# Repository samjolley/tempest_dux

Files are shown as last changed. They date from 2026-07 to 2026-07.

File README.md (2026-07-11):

# Tempest Dux

A wireless split ergonomic keyboard with an integrated trackball. Thirty-six keys, low-profile Choc switches, nice!nano v2, nice!view display, and a PMW3610 trackball on the right half.

This is my build. I did not design it from scratch, and the credits below matter.

## Lineage and credits

- **Ergonomics:** the dux family, Rae-Dux and Architeuthis Dux.
- **Base design and visual theme:** [thrly's Tempest](https://github.com/thrly/tempest).
- **Firmware base:** [Manna Harbour's Miryoku](https://github.com/manna-harbour/miryoku) for ZMK.
- **Trackball driver:** [badjeff's PMW3610 module](https://github.com/badjeff/zmk-pmw3610-driver).

## What is mine

Built on that lineage, my own contribution is:

- a custom PCB laid out with Ergogen and finished in KiCad (matrix, MCU, display, power, and the trackball cluster),
- the integrated PMW3610 trackball on the right half, its socket, and the printed housing,
- custom outlines and multi-layer 3D-printed plates and case,
- the ZMK firmware integration that makes the trackball a first-class input alongside the keys.

## Status

- **v0.6.56** boards fabricated and in assembly and bring-up.
- **v0.7.x** in progress: the reversible board architecture is dropped in favor of separate left and right files, with mounting-hole clearance, test points, and a dual-face ground pour on the errata list.

## Build log

I wrote up the design decisions, the failures, and what I would do differently here: <https://samjolley.com/writing/building-the-tempest-dux/>

## License

My original work here (the Ergogen config, the KiCad board, and my custom footprints) is released under the MIT License; see [LICENSE](LICENSE). Bundled third-party components keep their own licenses: the `ceoloide` Ergogen footprints under `ergogen/footprints/ceoloide/` retain the license headers in each file. This design builds on the prior art credited above, which carries its own terms where stated.

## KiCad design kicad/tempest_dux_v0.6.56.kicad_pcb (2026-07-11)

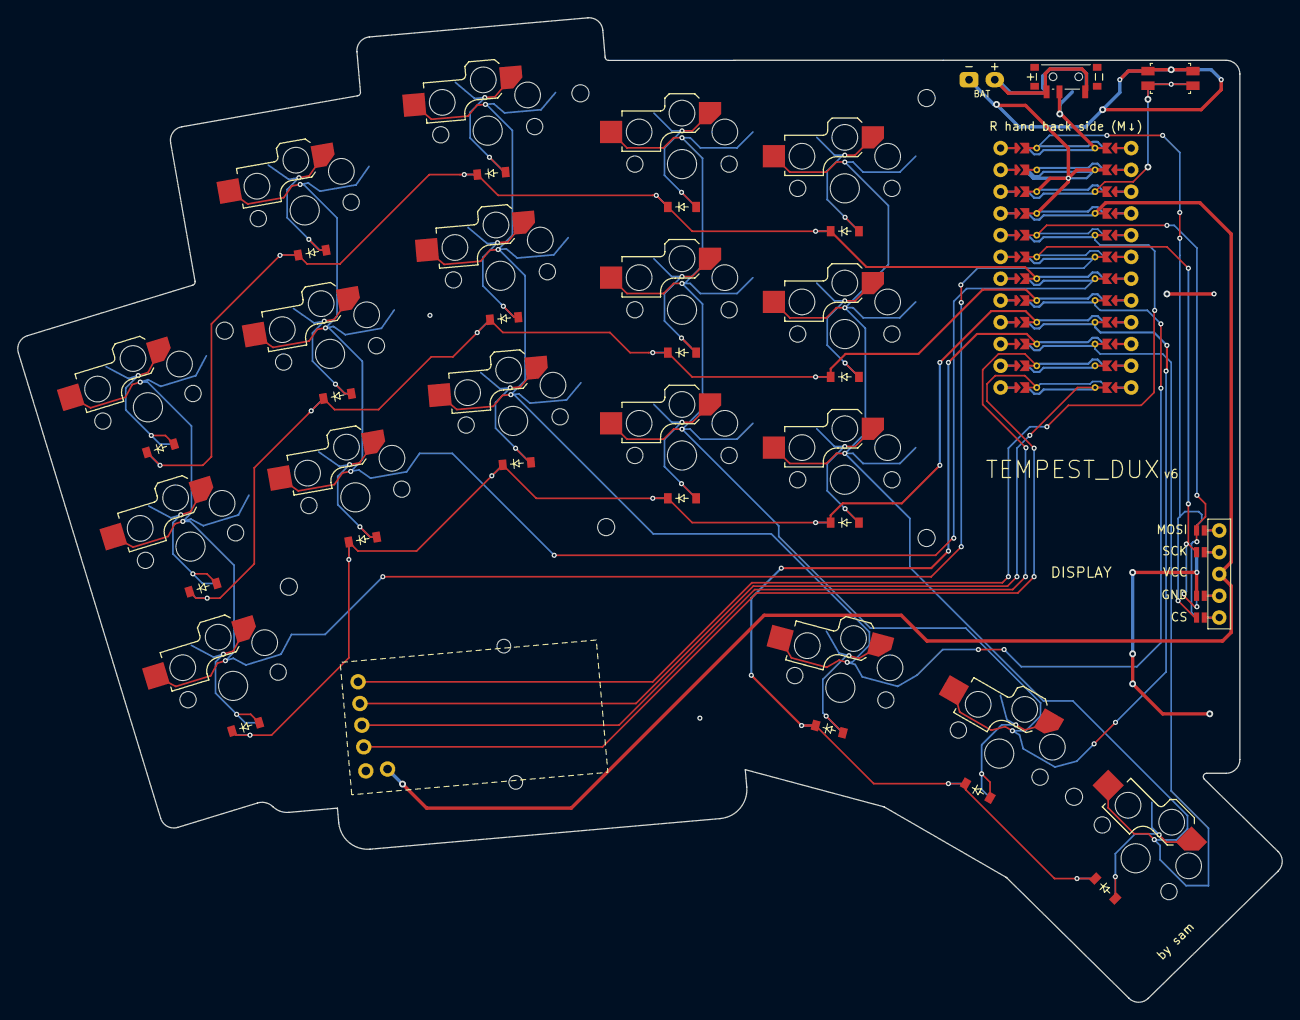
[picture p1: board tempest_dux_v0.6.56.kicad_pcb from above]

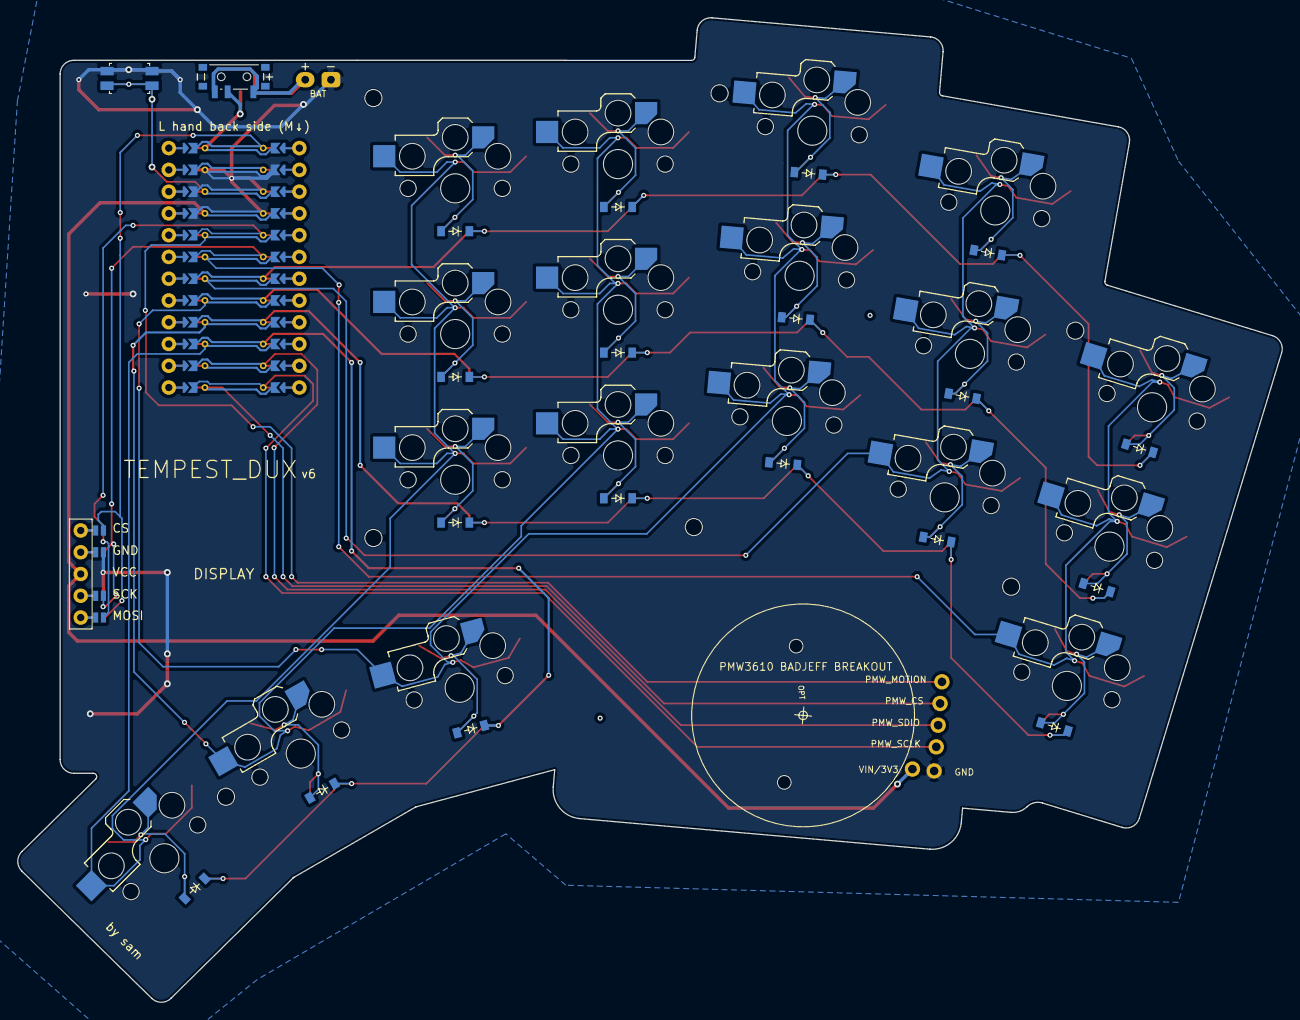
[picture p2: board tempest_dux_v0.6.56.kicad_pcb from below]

Board: 2 copper layers, 147.6 x 114.9 mm, 50 parts (18 on the bottom side), 43 nets.

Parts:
BAT1: battery_direct_solder_reversible
D1, D2, D3, D4, D5, D6, D7, D8, D9, D10, D11, D12, D13, D14, D15, D16, D17, D18: diode_tht_sod123
DISP1: display_nice_view
MCU1: mcu_nice_nano
MH1, MH2, MH3, MH4, MH5, MH6, MH7: mounting_hole_npth
PMW1: badjeff PMW3610 breakout socket; pmw3610_badjeff_socket
PWR1: power_switch_smd_side
RST1: reset_switch_smd_side
S1, S2, S3, S4, S5, S6, S7, S8, S9, S10, S11, S12, S13, S14, S15, S16, S17, S18: switch_choc_v1_v2
TB: keyball_34mm_case; keyball_trackball_case_34mm

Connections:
BAT_P: BAT1.2, PWR1.1, PWR1.3
CS: DISP1.14, DISP1.24, MCU1.124
DISP1_1: DISP1.1, DISP1.10, DISP1.23
DISP1_2: DISP1.2, DISP1.11, DISP1.22
DISP1_4: DISP1.4, DISP1.12, DISP1.21
DISP1_5: DISP1.5, DISP1.13, DISP1.20
GND: BAT1.1, DISP1.15, DISP1.25, MCU1.102, MCU1.121, MCU1.122, PMW1.GND, RST1.1, RST1.3
MOSI: DISP1.17, DISP1.27, MCU1.120
PMW_CS: MCU1.112, PMW1.CS
PMW_MOTION: MCU1.105, PMW1.MOTION
PMW_SCLK: MCU1.113, PMW1.SCLK
PMW_SDIO: MCU1.114, PMW1.SDIO
RAW: MCU1.101, PWR1.2
RST: MCU1.103, RST1.2, RST1.4
SCK: DISP1.16, DISP1.26, MCU1.119
VCC: DISP1.3, MCU1.104, PMW1.VIN
col_index: MCU1.109, S10.2, S11.2, S12.2, S17.2
col_inner: MCU1.110, S13.2, S14.2, S15.2, S18.2
col_middle: MCU1.108, S7.2, S8.2, S9.2, S16.2
col_pinky: MCU1.106, S1.2, S2.2, S3.2
col_ring: MCU1.107, S4.2, S5.2, S6.2
far_thumb-cluster: D18.2, S18.1
index_bottom: D10.2, S10.1
index_home: D11.2, S11.1
index_top: D12.2, S12.1
inner_bottom: D13.2, S13.1
inner_home: D14.2, S14.1
inner_top: D15.2, S15.1
mid_thumb-cluster: D17.2, S17.1
middle_bottom: D7.2, S7.1
middle_home: D8.2, S8.1
middle_top: D9.2, S9.1
near_thumb-cluster: D16.2, S16.1
pinky_bottom: D1.2, S1.1
pinky_home: D2.2, S2.1
pinky_top: D3.2, S3.1
ring_bottom: D4.2, S4.1
ring_home: D5.2, S5.1
ring_top: D6.2, S6.1
row_bottom: D1.1, D4.1, D7.1, D10.1, D13.1, MCU1.116
row_home: D2.1, D5.1, D8.1, D11.1, D14.1, MCU1.117
row_thumb: D16.1, D17.1, D18.1, MCU1.115
row_top: D3.1, D6.1, D9.1, D12.1, D15.1, MCU1.118

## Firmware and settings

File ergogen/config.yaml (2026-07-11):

# ===============================================================================
# TEMPEST_DUX - wireless split ergonomic keyboard with integrated PMW3610 trackball
# -------------------------------------------------------------------------------
# Lineage : rae-dux / track-dux column geometry (validated on Sam's daily driver)
# Stack   : ergogen v4.2.1 -> KiCad 8 -> JLCPCB ;  ZMK on nRF52840 (nice!nano v2)
# Repo    : https://github.com/samjolley/tempest_dux
#
# -- v0.7.x ARCHITECTURE: two dedicated single-sided boards (NOT reversible) -----
# The old reversible board (one gerber, flipped, peripherals DNP per side) is gone.
# v0.7 splits into two distinct single-sided gerbers generated from ONE points
# tree via an ergogen global mirror:
#
#     SOURCE hand (unprefixed pts: matrix_*, thumb_*) = LEFT  half = DISPLAY
#     MIRROR hand (mirror_* pts)                       = RIGHT half = TRACKBALL
#
# Handedness is verified, not assumed: in the source hand the pinky is leftmost and
# the inner column rightmost => that is the LEFT hand. The mirror is therefore the
# RIGHT hand, which carries the trackball. Do not swap these.
#
# -- MIRROR MECHANISM (read before editing geometry) ----------------------------
#   points.mirror: {ref: matrix_inner_home, distance: 160}  -> emits mirror_* pts.
#   ergogen does the reflection (x flipped, rotation negated), so there is NO manual
#   KiCad mirror step. The reflection is exact, incl. the asymmetric thumb cluster.
#
#   Hand isolation uses POSITIVE name regex on `where`:
#       source/left  : where: /^(matrix_|thumb_).*/
#       mirror/right : where: /^mirror_(matrix_|thumb_).*/
#   WARNING: do NOT use a negative lookahead like /^(?!mirror)/ - ergogen does not
#   honor it; it silently matches BOTH hands and the board spans both halves.
#   Single-point footprints use the matching ref prefix: left = matrix_inner_home,
#   right = mirror_matrix_inner_home, etc.
#
# -- ELECTRONICS / PINOUT (one ZMK keymap serves both halves) --------------------
#   Matrix rows : P4 P5 P6 P7          (identical both boards)
#   Matrix cols : P14 P15 P18 P19 P20  (identical both boards)
#   Display SPI : P1=CS  P2=MOSI P3=SCK                  -> LEFT board only
#   PMW3610 SPI : P10=CS P9=SCLK P8=SDIO P21=MOTION (3-wire) -> RIGHT board only
#   elec_* units (top of `units`) tune shared X/Y placement; elec_switch_right_x
#   adds a +1.4mm X nudge for the rotated SMD side power switch on the RIGHT only.
#
# -- OUTLINES & PLATES -----------------------------------------------------------
#   Source outlines (display_board_outline, keyboard_body, left_bottom_plate_outline)
#     = LEFT board (no trackball lobe).
#   right_* outlines (right_trackball_board_outline, right_bottom_plate_outline)
#     = RIGHT board (trackball lobe + cleanout).
#   Switch/top/TPU/back plates are built from the SOURCE (left) hand and are
#   symmetric - mirror them in the slicer for the right half. Bottom plates are
#   per-hand; only the right one has the trackball cleanout.
#
# -- PRE-ORDER CHECKLIST (custom footprints + DRC are not checkable from YAML) ----
#   [ ] 1:1 paper print BOTH halves; confirm key + trackball + thumb fit.
#   [ ] KiCad: switches/diodes/hotswap all on the same physical side (B.Cu) on BOTH
#       boards - confirm the mirror did not flip any footprint to F.Cu.
#   [ ] Confirm reverse_mount:true on the MCU is intended; check USB-C direction.
#   [ ] Verify right power switch (rotate 180 + elec_switch_right_x) position.
#   [ ] Custom footprints resolve: pmw3610_badjeff_socket, keyball_trackball_case_34mm,
#       TentingPuck, choc_hotswap_plate_cutout, smd_plate_cutout.
#   [ ] DRC clean on both boards (vias at 0.6/0.3mm sit at min annular ring).
#
# -- CHANGELOG -------------------------------------------------------------------
#   v0.7.5 : silk ver -> v0.7.5; branding text consolidated to side F; right reset
#            offset corrected (THT uses elec_switch_x, not SMD elec_switch_right_x).
#   v0.7.4 : ergogen global mirror; positive-regex hand isolation; handedness fixed
#            (trackball on mirror/right hand, display on source/left hand).
#   v0.7.0 : split reversible board into two single-sided boards; dropped reversible
#            footprints, MCU jumper field, and redundant vertical display.
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

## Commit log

2026-07-11 Replace upstream base with my Tempest Dux design; credit thrly and lineage
    Remove the upstream thrly/Tempest files and publish my own derivative work:
    the custom Ergogen config (v0.7.5, two single-sided boards with an integrated
    PMW3610 trackball), the KiCad board, and Choc hotswap footprints. Third-party
    ceoloide Ergogen footprints are kept with attribution. README credits thrly's
    Tempest, the Rae-Dux / Architeuthis Dux lineage, Miryoku, and badjeff's driver.
    [tempest-pcb-v-2.kicad_pcb, tempest-v2-36-key-case.stl, tempest-v2-36-key-plate.stl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]
2026-07-11 Remove machine-local KiCad .kicad_prl and gitignore it
    The .kicad_prl file is local editor state, not design source. Drop it from
    the public repo and ignore it going forward (flagged by independent review).
2026-07-11 Add MIT LICENSE and a README license section
    MIT is the ZMK keyboard community standard. Covers my original work (Ergogen
    config, KiCad board, custom footprints); bundled ceoloide footprints and the
    credited prior art retain their own terms.
